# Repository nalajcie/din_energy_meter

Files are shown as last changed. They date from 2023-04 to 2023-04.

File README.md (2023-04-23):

# DIN Energy Meter

**this is Work In Progress, not yet stable HW/SW**

DIN Energy Meter fitting 2-unit enclosure. Features
 - 6-circuit 3-phase 
 - CT-based (external current transformers needed)
 - ESP32 as a main MCU (WiFi)
 - ATM90E32 x2 as a metering IC
 - optional display + buttons

# Hardware

TODO: 3D model of full device
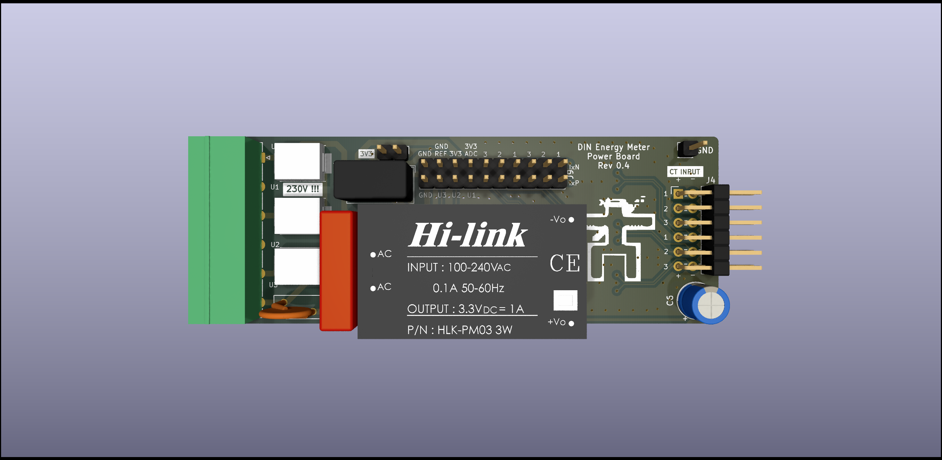
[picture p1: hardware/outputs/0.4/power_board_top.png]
Power Board top side

For details see [Hardware README](hardware/README.md)

# Current status

## Hardware

   - **Power board** - v0.4 prototype (not assembled)
   - **Metering board** - v0.4 prototype (assembled, in test)
   - **MCU board** - breadboard prototyping

## Software
   - basic **Metering board** test with Arduino framework done

# Inspiration

This project is heavily inspired by previous work, mainly:
 - [DIN_Rail_EnergyMonitor](https://github.com/whatnick/DIN_Rail_EnergyMonitor/) by [@whatnick](https://github.com/whatnick)
 - [Expandable 6 Channel ESP32 Energy Meter](https://github.com/CircuitSetup/Expandable-6-Channel-ESP32-Energy-Meter) by [CircuitSetup](https://github.com/CircuitSetup)

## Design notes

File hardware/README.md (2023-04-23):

# Kicad project of DIN Energy Meter

TODO: describe how to import into clean KiCad

Done in KiCad 7.0, multi-board design in hierarchical sheet. Splitting to multiple boards is done by kikit (see `split_boards.sh` for details).

# Power Board

 - Single-phase 230V AC to 3v3 DC
 - isolated 3v3 to 3v3 for power separation between ADCs and MCU
 - fliters and burden resistors for CT input
 - 2x10 2.54mm GPIO header for connecting with the **Metering Board**

Top side
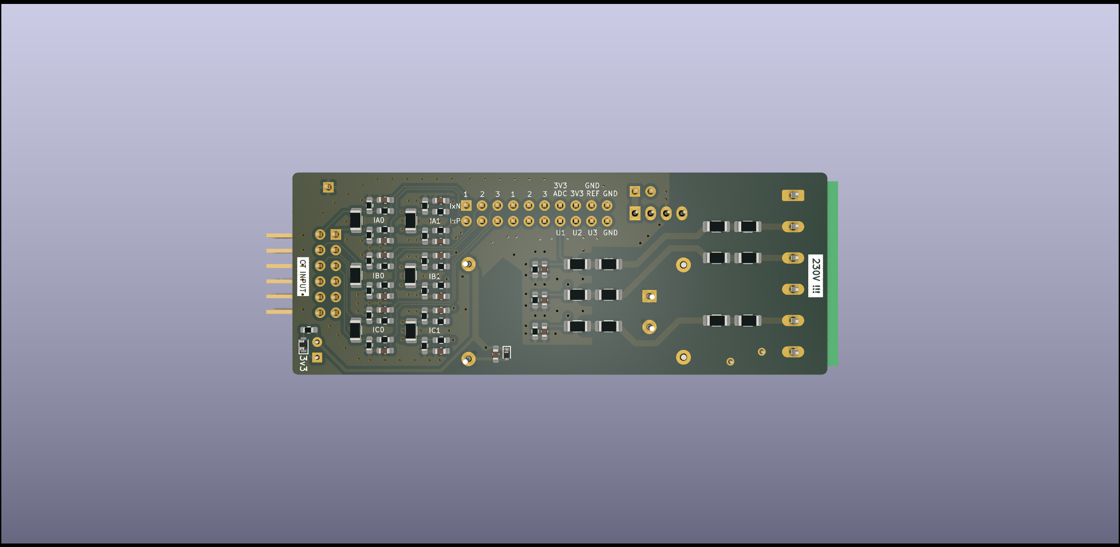
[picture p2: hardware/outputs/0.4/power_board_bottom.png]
Bottom side


# Metering Board

 - 2x ATM90E32 for energy measurement
 - CF1/2 on GPIO headers for accuracy measurement (CF3/4 on testpoints)
 - Power Manager selectors on solder jumpers
 - isolated SPI for MCU connection
 - 2x10 2.54mm GPIO header for connecting with the **Power Board**
 - 1x10 2.54mm GPIO header for connection with the **MCU board**

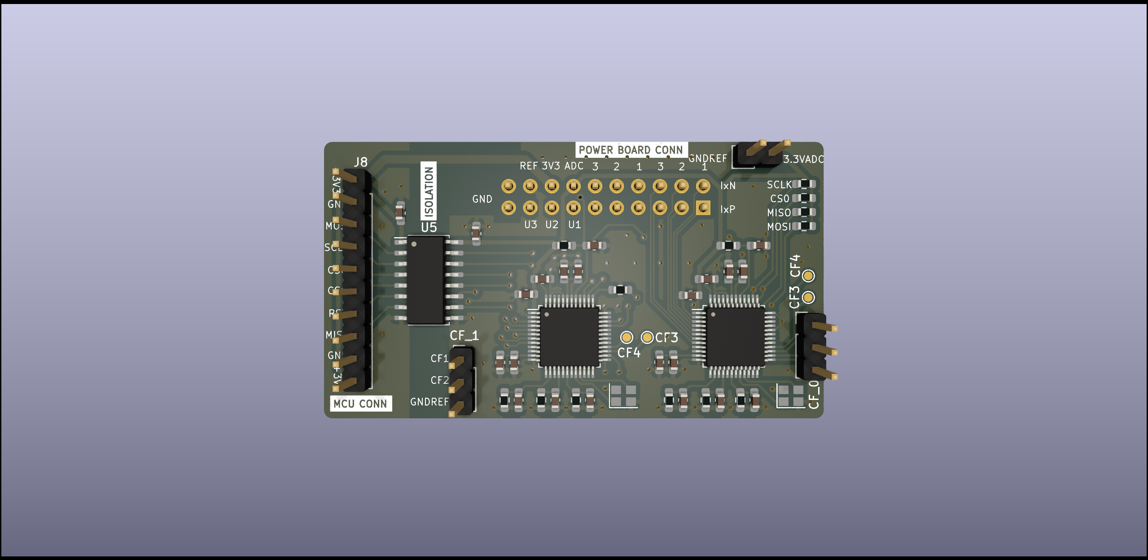
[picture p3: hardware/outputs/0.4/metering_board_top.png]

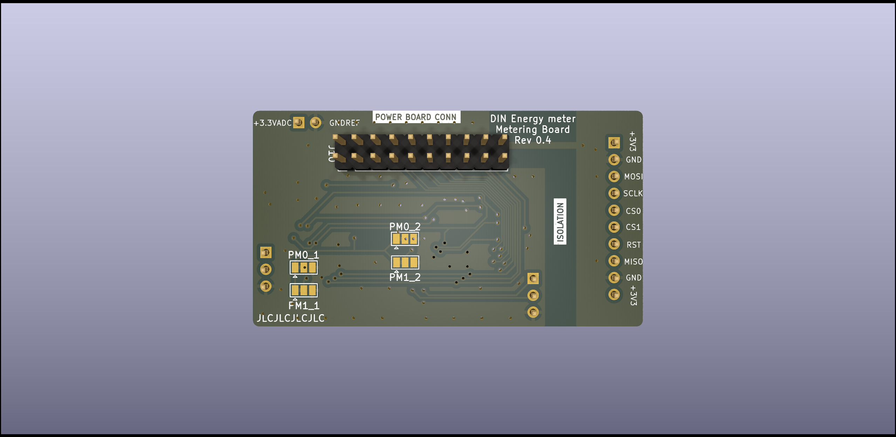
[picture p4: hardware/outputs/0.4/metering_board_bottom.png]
Botom side


# MCU Board

TODO

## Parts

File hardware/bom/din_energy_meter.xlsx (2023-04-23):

Prj: | din_energy_meter.xml |  |  |  | Board Qty: | 100
Co.: |  |  |  |  | Unit Cost: | $15.43
Prj date: | sob, 25 lut 2023, 14:41:14 |  |  |  | Total Cost: | $1543.05 |  |  |  |  | $1176.33 | 11 of 31 parts found |  |  |  |  | $1554.29 | 14 of 31 parts found |  |  |  |  | $1255.61 | 10 of 31 parts found |  |  |  |  | $0.00 | 0 of 31 parts found |  |  |  |  | $1572.30 | 16 of 31 parts found |  |  |  |  | $1421.20 | 13 of 31 parts found |  |  |  |  | $1427.90 | 6 of 31 parts found |  |  |  |  | $570.98 | 18 of 31 parts found
$ date: | 2023-02-25 14:41:14
Global Part Info |  |  |  |  |  |  | Arrow |  |  |  |  |  | Digi-Key |  |  |  |  |  | Farnell |  |  |  |  |  | LCSC |  |  |  |  |  | Mouser |  |  |  |  |  | Newark |  |  |  |  |  | RS Components |  |  |  |  |  | TME
Refs | Value | Footprint | Manf# | Qty | Unit$ | Ext$ | Avail | Purch | Unit$ | MOQ | Ext$ | Cat# | Avail | Purch | Unit$ | MOQ | Ext$ | Cat# | Avail | Purch | Unit$ | MOQ | Ext$ | Cat# | Avail | Purch | Unit$ | MOQ | Ext$ | Cat# | Avail | Purch | Unit$ | MOQ | Ext$ | Cat# | Avail | Purch | Unit$ | MOQ | Ext$ | Cat# | Avail | Purch | Unit$ | MOQ | Ext$ | Cat# | Avail | Purch | Unit$ | MOQ | Ext$ | Cat#
C1 | X2 100nF/275Vac | C_Rect_L18.0mm_W5.0mm_P15.00mm_FKS3_FKP3 | R46KI3100JHM1K | 100 | $0.194 | $19.40 |  |  |  |  |  |  | 1829 |  | $0.206 | 1 | $20.59 | 399-R46KI3100JHM1K-ND (https://octopart.com/click/track?ai=8078&sig=0d9e435&sid=459&ppid=20014343&vpid=658234598&ct=offers) | NonStk |  |  | 2000 |  | 2936551 (https://octopart.com/click/track?c=1&ai=8078&sig=0a215c6&sid=819&ppid=20014343&vpid=508109401&ct=offers) |  |  |  |  |  |  | 598 |  | $0.194 | 1 | $19.40 | 80-R46KI3100JHM1K (https://octopart.com/click/track?ai=8078&sig=02b7bfd&sid=2401&ppid=20014343&vpid=40138411&ct=offers) | NonStk |  |  | 2000 |  | 91AC0455 (https://octopart.com/click/track?c=1&ai=8078&sig=0f080cc&sid=2402&ppid=20014343&vpid=524279401&ct=offers)
C2 | 1uF | C_0603_1608Metric_Pad1.08x0.95mm_HandSolder | 0603B105K100CT | 100 | $0.019 | $1.90 | 32000 |  |  | 4000 |  | 0603B105K100CT (https://octopart.com/click/track?ai=8078&sig=085925f&sid=1106&ppid=23395230&vpid=435019830&ct=offers) | 19302 |  | $0.036 | 1 | $3.56 | 1292-0603B105K100CT-ND (https://octopart.com/click/track?ai=8078&sig=02cb6c4&sid=459&ppid=23395230&vpid=752151002&ct=offers) | 44000 |  | $0.043 | 10 | $4.31 | 3764119 (https://octopart.com/click/track?ai=8078&sig=0e46b60&sid=819&ppid=23395230&vpid=828845308&ct=offers) |  |  |  |  |  |  | 125 |  | $0.036 | 1 | $3.60 | 791-0603B105K100CT (https://octopart.com/click/track?ai=8078&sig=07ec92e&sid=2401&ppid=23395230&vpid=531631462&ct=offers) | 44000 |  | $0.019 | 1 | $1.90 | 50AJ6304 (https://octopart.com/click/track?ai=8078&sig=0c6b5c1&sid=2402&ppid=23395230&vpid=719400762&ct=offers) |  |  |  |  |  |  | 25900 |  | $0.023 | 100 | $2.26 | 0603B105K100CT (https://octopart.com/click/track?ai=8078&sig=080ccdd&sid=1532&ppid=23395230&vpid=709247350&ct=offers)
C3-C5,C10,C12,C15,C26,C28,C31,C39-C50 | 18nF | C_0603_1608Metric_Pad1.08x0.95mm_HandSolder | VJ0603Y183JXACW1BC | 2100 | $0.029 | $59.92 | 3590 |  | $0.050 | 1 | $103.95 | VJ0603Y183JXACW1BC (https://octopart.com/click/track?ai=8078&sig=0bca6ad&sid=1106&ppid=44635118&vpid=473543330&ct=offers) | 3810 |  | $0.078 | 1 | $164.35 | 720-VJ0603Y183JXACW1BCCT-ND (https://octopart.com/click/track?ai=8078&sig=06d9179&sid=459&ppid=44635118&vpid=720444692&ct=offers) |  |  |  |  |  |  |  |  |  |  |  |  | 3494 |  | $0.079 | 1 | $165.90 | 77-VJ0603Y183JXACBC (https://octopart.com/click/track?ai=8078&sig=06e8837&sid=2401&ppid=44635118&vpid=120235442&ct=offers) | NonStk |  |  | 4000 |  | 38AH3190 (https://octopart.com/click/track?c=1&ai=8078&sig=09761bd&sid=2402&ppid=44635118&vpid=588784234&ct=offers) |  |  |  |  |  |  | 4100 |  | $0.029 | 100 | $59.92 | VJ0603Y183JXACW1BC (https://octopart.com/click/track?ai=8078&sig=0d71c76&sid=1532&ppid=44635118&vpid=709245379&ct=offers)
C6 | 100uF | CP_Radial_D6.3mm_P2.50mm | ECEA0JKS101 | 100 | $0.101 | $10.08 | 2540 |  | $0.101 | 1 | $10.08 | ECE-A0JKS101 (https://octopart.com/click/track?ai=8078&sig=0f45c19&sid=1106&ppid=39480107&vpid=473390767&ct=offers) | 83067 |  | $0.153 | 1 | $15.30 | P958-ND (https://octopart.com/click/track?ai=8078&sig=0bcf554&sid=459&ppid=39480107&vpid=115650943&ct=offers) | 5006 |  | $0.128 | 1 | $12.82 | 1901988 (https://octopart.com/click/track?ai=8078&sig=0d6ed47&sid=11744&ppid=39480107&vpid=132556259&ct=offers) |  |  |  |  |  |  | NonStk |  | $0.122 | 1 | $12.20 | 667-ECE-A0JKS101 (https://octopart.com/click/track?c=1&ai=8078&sig=0b64973&sid=2401&ppid=39480107&vpid=116510917&ct=offers) | 37 |  | $0.131 | 1 | $13.10 | 55T0198 (https://octopart.com/click/track?ai=8078&sig=0df52cc&sid=2402&ppid=39480107&vpid=115392437&ct=offers) | 5135 |  | $0.158 | 5 | $15.81 | 116767 (https://octopart.com/click/track?ai=8078&sig=0fe3259&sid=10022&ppid=39480107&vpid=199096295&ct=offers) | 930 |  | $0.129 | 10 | $12.94 | ECEA0JKS101 (https://octopart.com/click/track?ai=8078&sig=0db0431&sid=1532&ppid=39480107&vpid=709128352&ct=offers)
C7,C23 | 4.7uF | C_0603_1608Metric_Pad1.08x0.95mm_HandSolder | 0603X475K100CT | 200 | $0.023 | $4.53 |  |  |  |  |  |  | 3990 |  | $0.058 | 1 | $11.52 | 1292-0603X475K100CT-ND (https://octopart.com/click/track?ai=8078&sig=0f582cf&sid=459&ppid=23760611&vpid=751474041&ct=offers) | NonStk |  | $0.049 | 10 | $9.82 | 2496929 (https://octopart.com/click/track?c=1&ai=8078&sig=0838894&sid=819&ppid=23760611&vpid=238084392&ct=offers) |  |  |  |  |  |  | 8157 |  | $0.060 | 1 | $12.00 | 791-0603X475K100CT (https://octopart.com/click/track?ai=8078&sig=07a0b57&sid=2401&ppid=23760611&vpid=531631706&ct=offers) |  |  |  |  |  |  |  |  |  |  |  |  | 63800 |  | $0.023 | 100 | $4.53 | 0603X475K100CT (https://octopart.com/click/track?ai=8078&sig=0551518&sid=1532&ppid=23760611&vpid=709247440&ct=offers)
C8,C9,C11,C14,C16-C18,C24,C25,C27,C30,C32 | 100nF | C_0603_1608Metric_Pad1.08x0.95mm_HandSolder | 06033C104KAT2A | 1200 | $0.010 | $11.64 | 8400 |  |  | 4000 |  | 06033C104KAT2A (https://octopart.com/click/track?ai=8078&sig=096d4ad&sid=1106&ppid=39590598&vpid=770669375&ct=offers) | 2354976 |  | $0.010 | 1 | $11.66 | 478-3714-1-ND (https://octopart.com/click/track?ai=8078&sig=069d21e&sid=459&ppid=39590598&vpid=770903829&ct=offers) | 472000 |  | $0.022 | 10 | $26.30 | 2530141 (https://octopart.com/click/track?ai=8078&sig=0d840be&sid=11744&ppid=39590598&vpid=772886336&ct=offers) |  |  |  |  |  |  | 858866 |  | $0.010 | 1 | $12.00 | 581-06033C104KAT2A (https://octopart.com/click/track?ai=8078&sig=0f1bb4d&sid=2401&ppid=39590598&vpid=771169314&ct=offers) | 364753 |  | $0.015 | 1 | $18.00 | 96M1263 (https://octopart.com/click/track?ai=8078&sig=06c45c6&sid=2402&ppid=39590598&vpid=772844523&ct=offers) | 248000 |  | $0.036 | 1000 | $43.12 | 1356595 (https://octopart.com/click/track?ai=8078&sig=0fe29cb&sid=10022&ppid=39590598&vpid=500983576&ct=offers) | 16200 |  | $0.010 | 100 | $11.64 | 06033C104KAT2A (https://octopart.com/click/track?ai=8078&sig=0d59a35&sid=1532&ppid=39590598&vpid=769977700&ct=offers)
C13,C29 | 10uF | C_0603_1608Metric_Pad1.08x0.95mm_HandSolder | 0603X106K6R3CT | 200 | $0.025 | $5.08 | 132000 |  |  | 4000 |  | 0603X106K6R3CT (https://octopart.com/click/track?ai=8078&sig=0fa8e71&sid=1106&ppid=50418793&vpid=418195488&ct=offers) | 31980 |  | $0.125 | 1 | $25.06 | 1292-0603X106K6R3CT-ND (https://octopart.com/click/track?ai=8078&sig=081b751&sid=459&ppid=50418793&vpid=752151067&ct=offers) | 20000 |  | $0.144 | 10 | $28.75 | 3764145 (https://octopart.com/click/track?ai=8078&sig=0025fef&sid=819&ppid=50418793&vpid=828845351&ct=offers) |  |  |  |  |  |  | 4000 |  | $0.130 | 1 | $26.00 | 791-0603X106K6R3CT (https://octopart.com/click/track?ai=8078&sig=0c4db15&sid=2401&ppid=50418793&vpid=531631688&ct=offers) | 20000 |  |  | 4000 |  | 50AJ6327 (https://octopart.com/click/track?ai=8078&sig=06d308f&sid=2402&ppid=50418793&vpid=719400785&ct=offers) |  |  |  |  |  |  | 3730 |  | $0.025 | 10 | $5.08 | 0603X106K6R3CT (https://octopart.com/click/track?ai=8078&sig=043e844&sid=1532&ppid=50418793&vpid=878166210&ct=offers)
D1 | D_TVS | D_SOD-523 | ESD5Z3V3 | 100 | $0.031 | $3.05 |  |  |  |  |  |  |  |  |  |  |  |  |  |  |  |  |  |  |  |  |  |  |  |  | 12308 |  | $0.182 | 1 | $18.20 | 637-ESD5Z3V3 (https://octopart.com/click/track?ai=8078&sig=066cd02&sid=2401&ppid=93126590&vpid=808546162&ct=offers) |  |  |  |  |  |  |  |  |  |  |  |  | 1450 |  | $0.031 | 20 | $3.05 | ESD5Z3V3-DIO (https://octopart.com/click/track?ai=8078&sig=0500459&sid=1532&ppid=93126590&vpid=707850701&ct=offers)
D2 | 3v3 | D_0603_1608Metric | RF-GNB191TS-CF | 100 | $0.039 | $3.86 |  |  |  |  |  |  |  |  |  |  |  |  |  |  |  |  |  |  |  |  |  |  |  |  |  |  |  |  |  |  |  |  |  |  |  |  |  |  |  |  |  |  | 8668 |  | $0.039 | 10 | $3.86 | RF-GNB191TS-CF (https://octopart.com/click/track?ai=8078&sig=0cbc811&sid=1532&ppid=117692161&vpid=712317848&ct=offers)
F1 | 120mA polyfuse | Fuse_BelFuse_0ZRE0012FF_L8.3mm_W3.8mm | 0ZRE0012FF1C (https://www.tme.eu/Document/907938f7193985bd7926321a5eeb36df/0ZRE+Sep2016.pdf) | 100 | $0.236 | $23.62 | 5988 |  | $0.236 | 1 | $23.62 | 0ZRE0012FF1C (https://octopart.com/click/track?ai=8078&sig=0877e9d&sid=1106&ppid=16963854&vpid=104967227&ct=offers) | 15684 |  | $0.276 | 1 | $27.62 | 507-1350-ND (https://octopart.com/click/track?ai=8078&sig=06a94dc&sid=459&ppid=16963854&vpid=33596542&ct=offers) |  |  |  |  |  |  |  |  |  |  |  |  | 8266 |  | $0.277 | 1 | $27.70 | 530-0ZRE0012FF1C (https://octopart.com/click/track?ai=8078&sig=084db7e&sid=2401&ppid=16963854&vpid=210394555&ct=offers) | NonStk |  |  | 2000 |  | 58AC4734 (https://octopart.com/click/track?c=1&ai=8078&sig=0ab400e&sid=2402&ppid=16963854&vpid=508524160&ct=offers) |  |  |  |  |  |  | 798 |  | $0.250 | 5 | $25.03 | 0ZRE0012FF1C (https://octopart.com/click/track?ai=8078&sig=0e4f024&sid=1532&ppid=16963854&vpid=707800490&ct=offers)
IC1,IC2 | ATM90E32AS | TQFP-48_7x7mm_P0.5mm | ATM90E36A-AU-Y (http://ww1.microchip.com/downloads/en/devicedoc/Atmel-46003-SE-M90E32AS-Datasheet.pdf) | 200 | $4.765 | $953.00 | 8 |  | $4.765 | 1 | $953.00 | ATM90E36A-AU-Y (https://octopart.com/click/track?ai=8078&sig=0fd6b16&sid=1106&ppid=77759767&vpid=473293160&ct=offers) | NonStk |  | $4.800 | 1 | $960.00 | ATM90E36A-AU-Y-ND (https://octopart.com/click/track?ai=8078&sig=0e8341e&sid=459&ppid=77759767&vpid=408716065&ct=offers) | 490 |  | $5.055 | 1 | $1010.94 | 2851659 (https://octopart.com/click/track?ai=8078&sig=0a1cbe9&sid=11744&ppid=77759767&vpid=478775971&ct=offers) |  |  |  |  |  |  | NonStk |  | $4.800 | 1 | $960.00 | 556-ATM90E36A-AU-Y (https://octopart.com/click/track?c=1&ai=8078&sig=0b3a90c&sid=2401&ppid=77759767&vpid=408978359&ct=offers) | 490 |  | $4.800 | 1 | $960.00 | 55AC1236 (https://octopart.com/click/track?ai=8078&sig=0ea5cb5&sid=2402&ppid=77759767&vpid=477464294&ct=offers) | 304 |  | $5.767 | 2 | $1153.48 | 1773688P (https://octopart.com/click/track?ai=8078&sig=0ebb1fb&sid=10022&ppid=77759767&vpid=576284179&ct=offers) | NonStk |  |  | 250 |  | ATM90E36A-AU-Y (https://octopart.com/click/track?c=1&ai=8078&sig=0d923a4&sid=1532&ppid=77759767&vpid=709079543&ct=offers)
J1 | PWR | PinHeader_1x02_P2.54mm_Vertical |  | 100
J2 | PHASE_CONN | PhoenixContact_MC_1,5_6-G-5.08_1x06_P5.08mm_Horizontal |  | 100
J3 | GNDREF | PinHeader_1x01_P2.54mm_Vertical |  | 100
J4 | Conn_02x06_Odd_Even | PinHeader_2x06_P2.54mm_Horizontal |  | 100
J7,J11 | CF_${IC} | PinHeader_1x03_P2.54mm_Vertical |  | 200
J8 | MCU_CONN | PinHeader_1x10_P2.54mm_Vertical |  | 100
J9,J10 | PowerBoard | PinHeader_2x10_P2.54mm_Vertical |  | 200
J12 | Conn_01x02 | PinHeader_1x02_P2.54mm_Vertical |  | 100
L1 | 270 nH | L_1206_3216Metric | AIML-1206-R27K-T | 100 | $0.088 | $8.82 | 21983 |  | $0.088 | 1 | $8.82 | AIML-1206-R27K-T (https://octopart.com/click/track?ai=8078&sig=0644fb9&sid=1106&ppid=20100824&vpid=507086374&ct=offers) | 14846 |  | $0.189 | 1 | $18.89 | 535-11684-1-ND (https://octopart.com/click/track?ai=8078&sig=05738c4&sid=459&ppid=20100824&vpid=44466968&ct=offers) |  |  |  |  |  |  |  |  |  |  |  |  | 23804 |  | $0.151 | 1 | $15.10 | 815-AIML-1206-R27KT (https://octopart.com/click/track?ai=8078&sig=0473fb4&sid=2401&ppid=20100824&vpid=269003347&ct=offers) | NonStk |  |  | 30000 |  | 96W8210 (https://octopart.com/click/track?c=1&ai=8078&sig=0ca56a2&sid=2402&ppid=20100824&vpid=95831973&ct=offers)
PS1 | HLK-PM03 | Converter_ACDC_HiLink_HLK-PMxx | HLK-PM03 (http://www.hlktech.net/product_detail.php?ProId=59) | 100
PS2 | AM1SS-0303S | Converter_DCDC_SIP4_THT | AM1SS-0303S-NZ (https://power.murata.com/pub/data/power/ncl/kdc_mee1.pdf) | 100 | $2.276 | $227.58 |  |  |  |  |  |  |  |  |  |  |  |  |  |  |  |  |  |  |  |  |  |  |  |  |  |  |  |  |  |  | NonStk |  | $2.440 | 1 | $244.00 | 27AK8762 (https://octopart.com/click/track?c=1&ai=8078&sig=0dc0d35&sid=2402&ppid=47202323&vpid=801580070&ct=offers) |  |  |  |  |  |  | 238 |  | $2.276 | 1 | $227.58 | AM1SS-0303S-NZ (https://octopart.com/click/track?ai=8078&sig=0dd2fc3&sid=1532&ppid=47202323&vpid=707755244&ct=offers)
R1-R12 | 220K | R_1206_3216Metric_Pad1.30x1.75mm_HandSolder | ARG06DTC2203 | 1200 | $0.017 | $20.45 |  |  |  |  |  |  |  |  |  |  |  |  |  |  |  |  |  |  |  |  |  |  |  |  |  |  |  |  |  |  |  |  |  |  |  |  |  |  |  |  |  |  | 5000 |  | $0.017 | 100 | $20.45 | ARG1206-220K-0.5% (https://octopart.com/click/track?ai=8078&sig=0355751&sid=1532&ppid=81881808&vpid=709238049&ct=offers)
R13-R18,R34-R36,R72-R77,R87-R92 | 1K | R_0603_1608Metric_Pad0.98x0.95mm_HandSolder | AC0603FR-071KL | 2100 | $0.004 | $9.16 | 10000 |  | $0.037 | 1 | $76.86 | AC0603FR-071KL (https://octopart.com/click/track?ai=8078&sig=0da5267&sid=1106&ppid=21711097&vpid=712942385&ct=offers) | 787994 |  | $0.005 | 1 | $9.72 | 311-1KLDCT-ND (https://octopart.com/click/track?ai=8078&sig=0beb677&sid=459&ppid=21711097&vpid=48251721&ct=offers) | 694910 |  | $0.005 | 10 | $10.06 | 3495238 (https://octopart.com/click/track?ai=8078&sig=02465d4&sid=819&ppid=21711097&vpid=653862114&ct=offers) |  |  |  |  |  |  | 1569620 |  | $0.005 | 1 | $10.50 | 603-AC0603FR-071KL (https://octopart.com/click/track?ai=8078&sig=0c7dd51&sid=2401&ppid=21711097&vpid=47327394&ct=offers) | 696330 |  | $0.009 | 1 | $18.90 | 49AK0481 (https://octopart.com/click/track?c=1&ai=8078&sig=08c4470&sid=2402&ppid=21711097&vpid=833155641&ct=offers) | 76000 |  | $0.012 | 500 | $25.15 | 1978033 (https://octopart.com/click/track?ai=8078&sig=042dc69&sid=10022&ppid=21711097&vpid=625435411&ct=offers) | 48300 |  | $0.004 | 100 | $9.16 | AC0603FR-071KL (https://octopart.com/click/track?ai=8078&sig=0dff357&sid=1532&ppid=21711097&vpid=709256810&ct=offers)
R19,R37,R52-R56 | 10K | R_0603_1608Metric_Pad0.98x0.95mm_HandSolder | AC0603FR-0710KL | 700 | $0.009 | $6.30 | 44979 |  |  | 5000 |  | AC0603FR-0710KL (https://octopart.com/click/track?ai=8078&sig=078ca9b&sid=1106&ppid=21711091&vpid=525146659&ct=offers) | 1620273 |  | $0.010 | 1 | $7.21 | 311-10KLDCT-ND (https://octopart.com/click/track?ai=8078&sig=048749f&sid=459&ppid=21711091&vpid=48251715&ct=offers) | 1066430 |  | $0.010 | 10 | $6.71 | 3495224 (https://octopart.com/click/track?ai=8078&sig=035a96c&sid=819&ppid=21711091&vpid=653862088&ct=offers) |  |  |  |  |  |  | 1315817 |  | $0.011 | 1 | $7.70 | 603-AC0603FR-0710KL (https://octopart.com/click/track?ai=8078&sig=0890030&sid=2401&ppid=21711091&vpid=47327388&ct=offers) | 1050430 |  | $0.009 | 1 | $6.30 | 82AH6475 (https://octopart.com/click/track?ai=8078&sig=08fa70f&sid=2402&ppid=21711091&vpid=655849759&ct=offers) | 41500 |  | $0.013 | 500 | $9.22 | 1978014 (https://octopart.com/click/track?ai=8078&sig=062ae61&sid=10022&ppid=21711091&vpid=625435384&ct=offers) | 68300 |  | $0.015 | 100 | $10.82 | AC0603FR-0710KL (https://octopart.com/click/track?ai=8078&sig=0df3789&sid=1532&ppid=21711091&vpid=709256805&ct=offers)
R22 | 27 | R_0603_1608Metric_Pad0.98x0.95mm_HandSolder | 0603SAF270JT5E | 100 | $0.013 | $1.32 |  |  |  |  |  |  |  |  |  |  |  |  |  |  |  |  |  |  |  |  |  |  |  |  | NonStk |  |  | 10000 |  | 303-0603SAF270JT5E (https://octopart.com/click/track?c=1&ai=8078&sig=07bcc4d&sid=2401&ppid=50586927&vpid=848260658&ct=offers) |  |  |  |  |  |  |  |  |  |  |  |  | 213700 |  | $0.013 | 100 | $1.32 | SMD0603-27R-1% (https://octopart.com/click/track?ai=8078&sig=099bb44&sid=1532&ppid=50586927&vpid=709151428&ct=offers)
R63-R65,R78-R80 | 20 | R_1206_3216Metric | ARG06DTC0200 | 600 | $0.031 | $18.69 |  |  |  |  |  |  |  |  |  |  |  |  |  |  |  |  |  |  |  |  |  |  |  |  |  |  |  |  |  |  |  |  |  |  |  |  |  |  |  |  |  |  | 9100 |  | $0.031 | 100 | $18.69 | ARG1206-20R-0.5% (https://octopart.com/click/track?ai=8078&sig=08034d3&sid=1532&ppid=117725499&vpid=716008692&ct=offers)
R66-R71,R81-R86 | 2.4 | R_0603_1608Metric_Pad0.98x0.95mm_HandSolder |  | 1200
RV1-RV3 | 275 VAC | CU3225 | B72650M0271K072 | 300 | $0.188 | $56.52 | 5000 |  |  | 1000 |  | B72650M0271K072 (https://octopart.com/click/track?ai=8078&sig=0b6aa59&sid=1106&ppid=11760851&vpid=864848381&ct=offers) | 42434 |  | $0.580 | 1 | $174.02 | 495-2388-1-ND (https://octopart.com/click/track?ai=8078&sig=0add487&sid=459&ppid=11760851&vpid=441542126&ct=offers) | 1994 |  | $0.486 | 1 | $145.89 | 9958533 (https://octopart.com/click/track?ai=8078&sig=064fd41&sid=11744&ppid=11760851&vpid=194181755&ct=offers) |  |  |  |  |  |  | 46843 |  | $0.530 | 1 | $159.00 | 871-B72650M0271K072 (https://octopart.com/click/track?ai=8078&sig=0b16769&sid=2401&ppid=11760851&vpid=42614561&ct=offers) | NonStk |  | $0.530 | 1 | $159.00 | 34M5347 (https://octopart.com/click/track?c=1&ai=8078&sig=08f2c19&sid=2402&ppid=11760851&vpid=198960057&ct=offers) | 2000 |  | $0.604 | 5 | $181.11 | 7691993 (https://octopart.com/click/track?ai=8078&sig=0aa7f29&sid=10022&ppid=11760851&vpid=229316461&ct=offers) | 19160 |  | $0.188 | 5 | $56.52 | B72650M271K72 (https://octopart.com/click/track?ai=8078&sig=0f6f2ac&sid=1532&ppid=11760851&vpid=707881342&ct=offers)
U5 | Π161M31 | SOIC-16_4.55x10.3mm_P1.27mm | PAI161M31 (https://www.tme.eu/Document/adeb9fdb0591ca86c726a8f870a6b0a3/PAI16xM3x_PAI16xM6x.pdf) | 100
Y1,Y2 | 16.384MHz | Crystal_SMD_2520-4Pin_2.5x2.0mm | LFXTAL069395CUTT (https://www.tme.eu/Document/746e65f8387f34db343fe6d2f6181449/LFXTAL069395CUTT.pdf) | 200 | $0.491 | $98.14 |  |  |  |  |  |  | 16968 |  | $0.524 | 1 | $104.78 | 1923-1355-1-ND (https://octopart.com/click/track?ai=8078&sig=0442bfd&sid=459&ppid=65452348&vpid=705503096&ct=offers) |  |  |  |  |  |  |  |  |  |  |  |  | 65 |  | $0.615 | 1 | $123.00 | 449-LFXTAL069395CUTT (https://octopart.com/click/track?ai=8078&sig=0ca7c83&sid=2401&ppid=65452348&vpid=456356865&ct=offers) |  |  |  |  |  |  |  |  |  |  |  |  | 100 |  | $0.491 | 1 | $98.14 | 16.3840M-CFPX-218 (https://octopart.com/click/track?ai=8078&sig=038e80a&sid=1532&ppid=65452348&vpid=709031548&ct=offers)
 | Used currency rates: |  |  |  | Total Purchase: | $0.00 | Buy here (https://www.arrow.com/en/bom-tool/) |  |  |  | $0.00 |  | Buy here (https://www.digikey.com/ordering/shoppingcart) |  |  |  | $0.00 |  | Buy here (https://fr.farnell.com/en-FR/quick-order?isQuickPaste=true) |  |  |  | $0.00 |  | Buy here (https://lcsc.com/bom.html) |  |  |  | $0.00 |  | Buy here (https://mouser.com/bom/) |  |  |  | $0.00 |  | Buy here (https://www.newark.com/quick-order?isQuickPaste=true) |  |  |  | $0.00 |  | Buy here (https://uk.rs-online.com/web/mylists/manualQuotes.html?method=showEnquiryCreationPage&mode=new) |  |  |  | $0.00 |  | Buy here (https://www.tme.eu/en/Profile/QuickBuy/load.html) |  |  |  | $0.00
 | USD($)/GBP(£): | 1.197801575 |  |  | Purchase description: |  |  |  |  |  |  |  |  |  |  |  |  |  |  |  |  |  |  |  |  | Copy this header and order to a CSV file and use it for JLCPCB manufacturer PCB house. The multipart components that use "#" symbol are not allowed by JLCPCB.
KiCost® v1.1.15

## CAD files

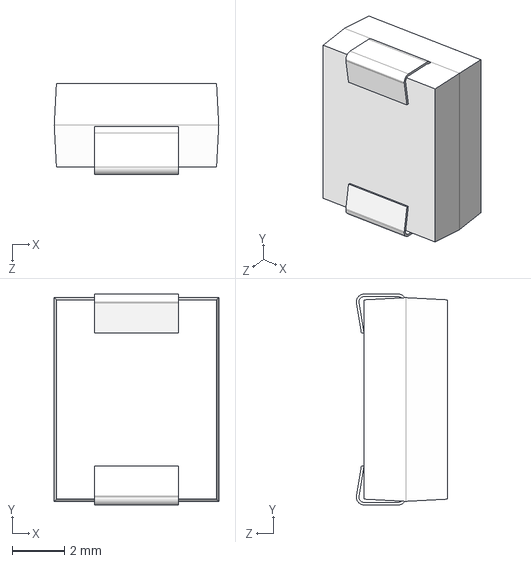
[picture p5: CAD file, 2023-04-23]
hardware/3D/B72650M0271K072.stp
6.30 x 8.08 x 3.49 mm

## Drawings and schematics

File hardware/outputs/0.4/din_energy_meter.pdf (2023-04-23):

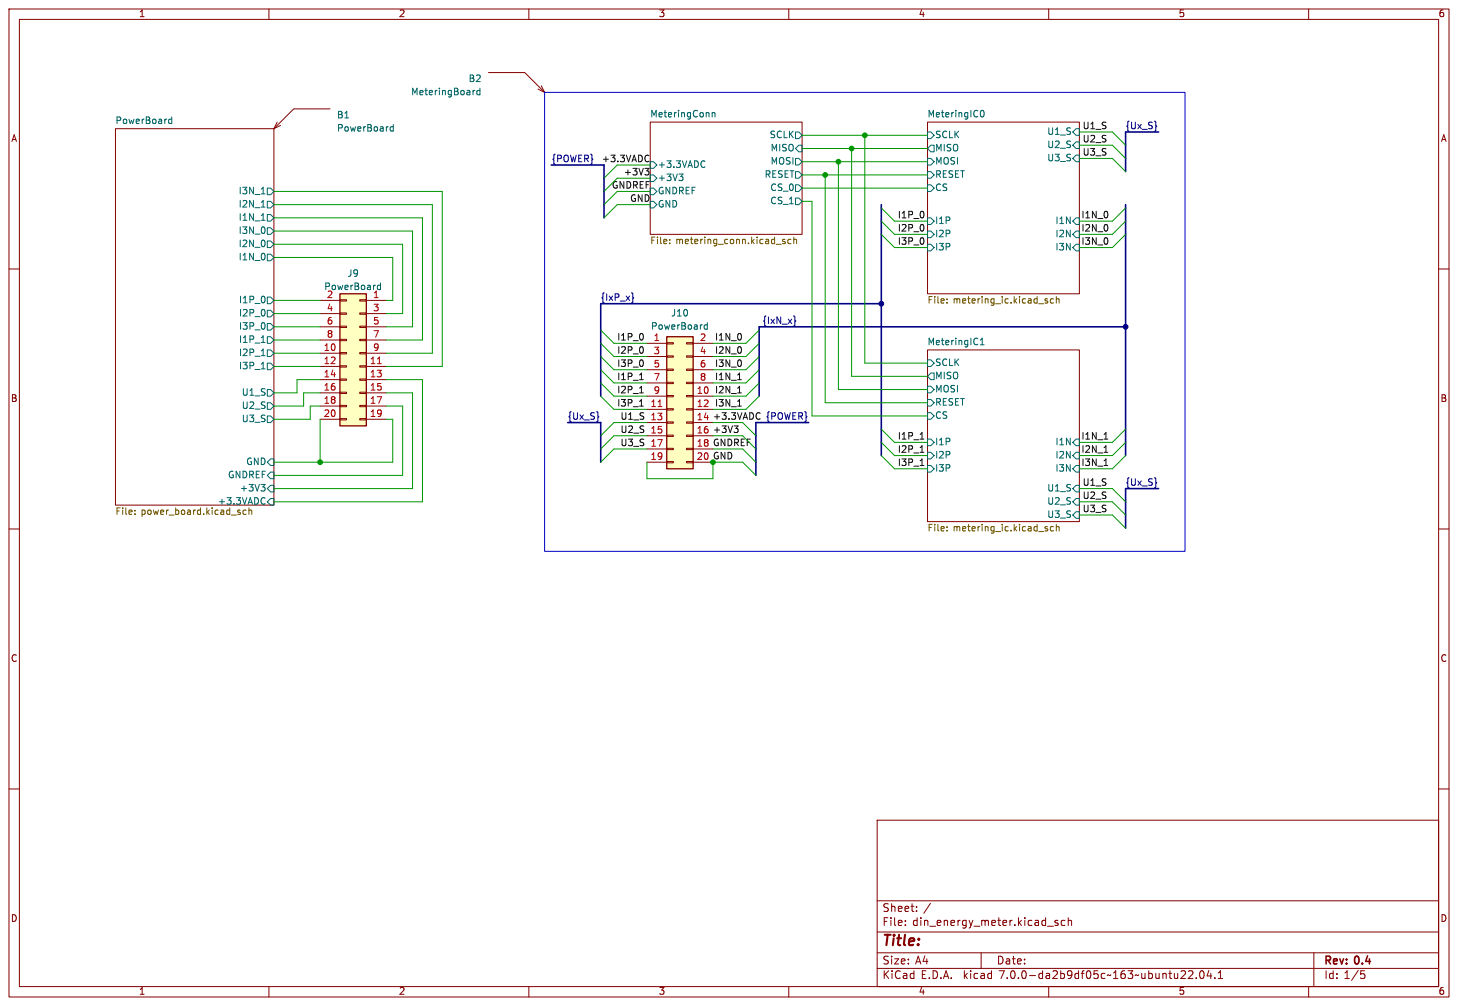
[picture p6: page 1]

CSRESET MeteringIC0 File: metering_ic.kicad_sch SCLK MISO MOSI CS_0 CS_1 +3V3 GND GNDREF

Id: 1/5 Title: File: din_energy_meter.kicad_sch Sheet: /

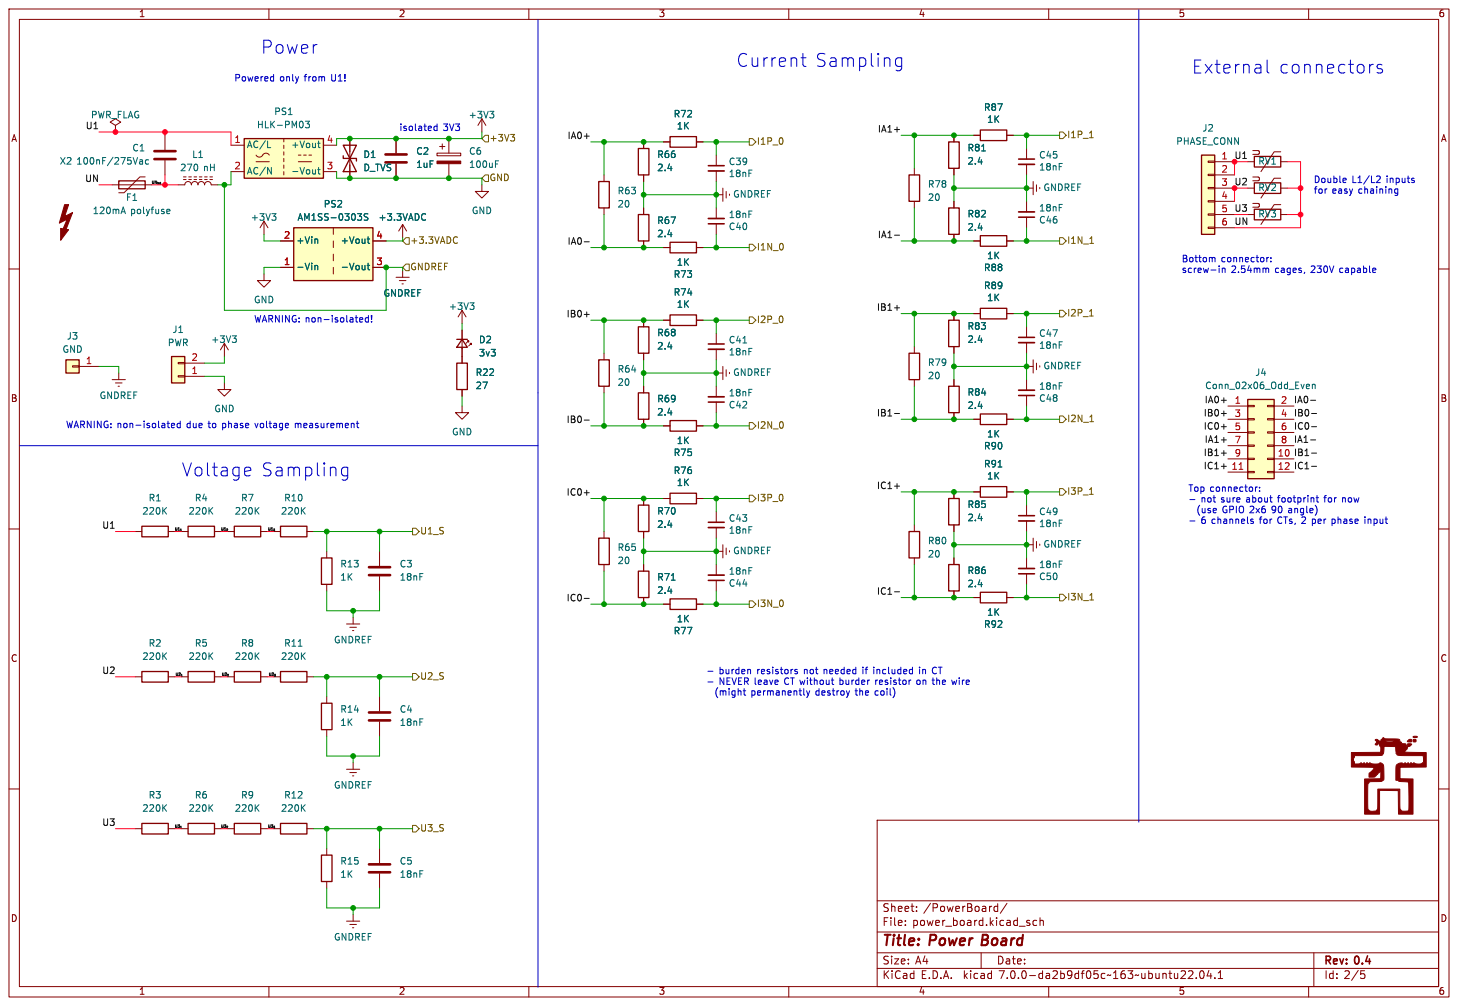
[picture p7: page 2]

- burden resistors not needed if included in CT
- NEVER leave CT without burder resistor on the wire

Id: 2/5 Title: Power Board

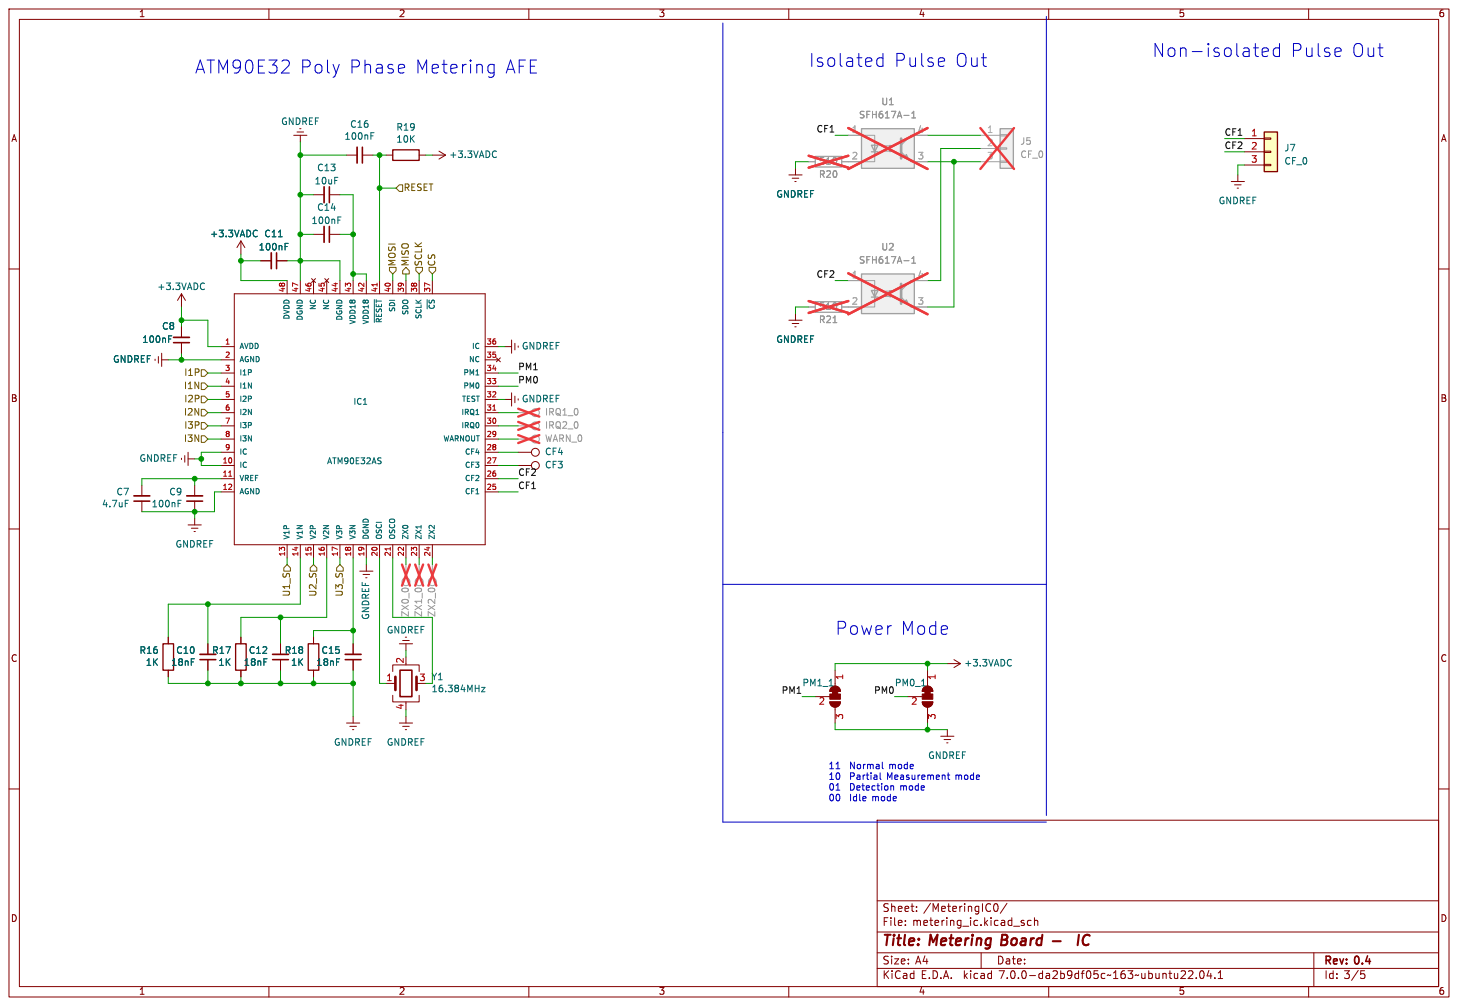
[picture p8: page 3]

00 Idle mode Power Mode

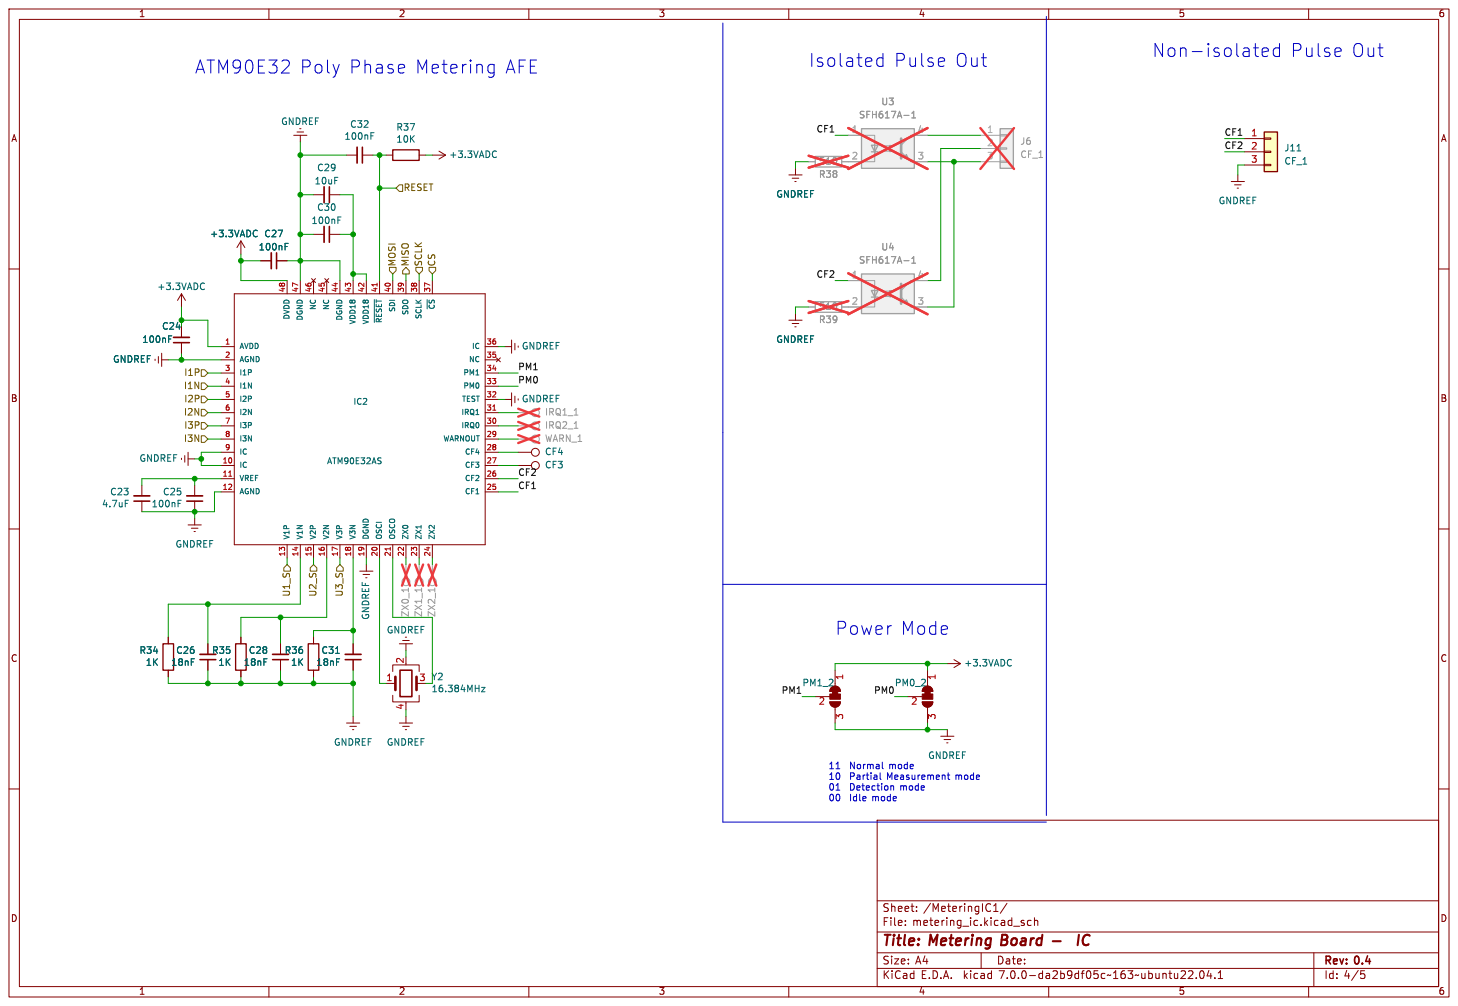
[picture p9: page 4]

ATM90E32 Poly Phase Metering AFE
18nF GNDREF C24

00 Idle mode Power Mode

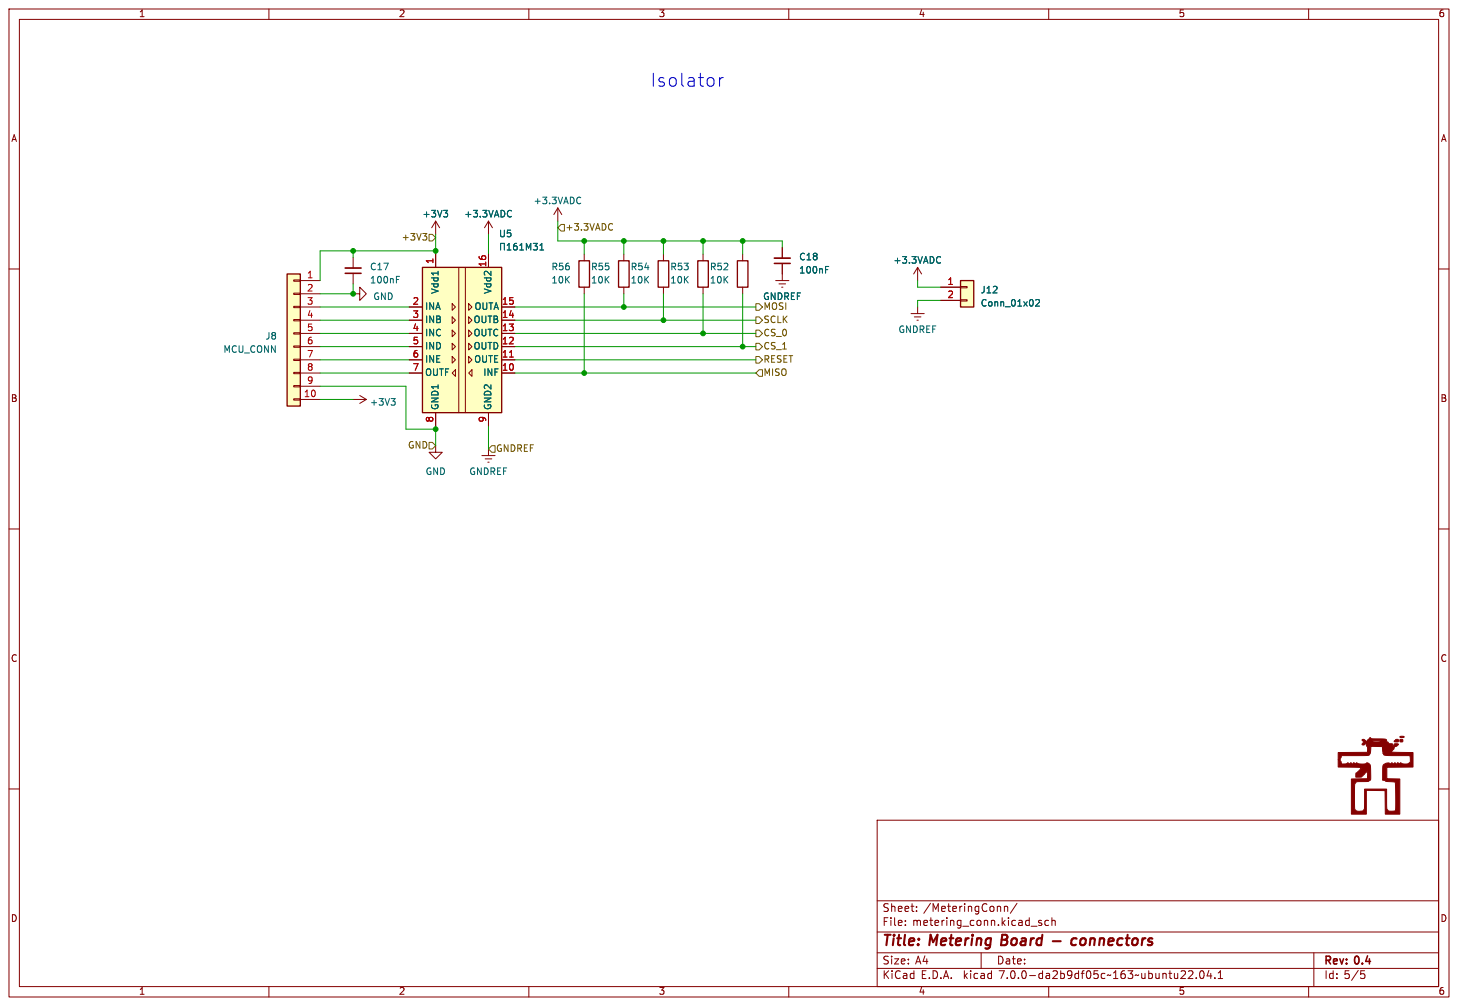
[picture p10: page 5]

File: metering_conn.kicad_sch Sheet: /MeteringConn/
Id: 5/5 Title: Metering Board - connectors

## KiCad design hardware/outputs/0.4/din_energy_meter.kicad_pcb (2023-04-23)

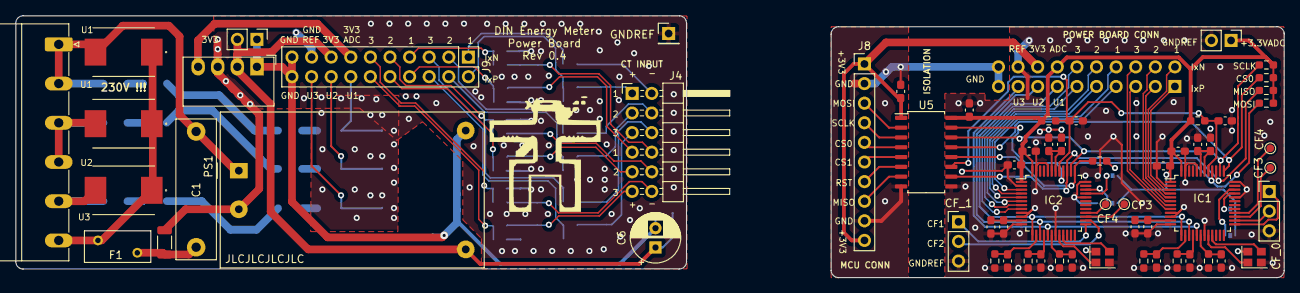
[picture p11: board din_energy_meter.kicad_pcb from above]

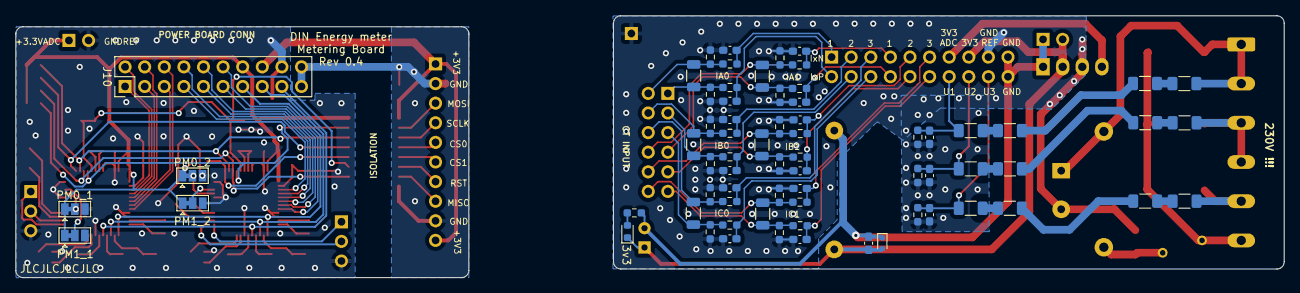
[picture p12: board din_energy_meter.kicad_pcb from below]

Board: 2 copper layers, 164.3 x 33.9 mm, 134 parts (69 on the bottom side), 99 nets.

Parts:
B1: PowerBoard; Board
B2: MeteringBoard; Board
C1: X2 100nF/275Vac; C_Rect_L18.0mm_W5.0mm_P15.00mm_FKS3_FKP3
C2: 1uF; C_0603_1608Metric_Pad1.08x0.95mm_HandSolder
C3, C4, C5, C10, C12, C15, C26, C28, C31, C39, C40, C41, C42, C43, C44, C45, C46, C47, C48, C49, C50: 18nF; C_0603_1608Metric_Pad1.08x0.95mm_HandSolder
C6: 100uF; CP_Radial_D6.3mm_P2.50mm
C7, C23: 4.7uF; C_0603_1608Metric_Pad1.08x0.95mm_HandSolder
C8, C9, C11, C14, C16, C17, C18, C24, C25, C27, C30, C32: 100nF; C_0603_1608Metric_Pad1.08x0.95mm_HandSolder
C13, C29: 10uF; C_0603_1608Metric_Pad1.08x0.95mm_HandSolder
D1: D_TVS; D_SOD-523
D2: 3v3; D_0603_1608Metric
F1: 120mA polyfuse; Fuse_BelFuse_0ZRE0012FF_L8.3mm_W3.8mm
G1: darwiniajack
IC1, IC2: ATM90E32AS; TQFP-48_7x7mm_P0.5mm
J1: PWR; PinHeader_1x02_P2.54mm_Vertical
J2: PHASE_CONN; PhoenixContact_MC_1,5_6-G-5.08_1x06_P5.08mm_Horizontal
J3: GNDREF; PinHeader_1x01_P2.54mm_Vertical
J4: Conn_02x06_Odd_Even; PinHeader_2x06_P2.54mm_Horizontal
J7, J11: CF_${IC}; PinHeader_1x03_P2.54mm_Vertical
J8: MCU_CONN; PinHeader_1x10_P2.54mm_Vertical
J9, J10: PowerBoard; PinHeader_2x10_P2.54mm_Vertical
J12: Conn_01x02; PinHeader_1x02_P2.54mm_Vertical
L1: 270 nH; L_1206_3216Metric
PM0_1, PM0_2, PM1_1, PM1_2: SolderJumper_3_Bridged12; SolderJumper-3_P1.3mm_Bridged12_Pad1.0x1.5mm
PS1: HLK-PM03; Converter_ACDC_HiLink_HLK-PMxx
PS2: AM1SS-0303S; Converter_DCDC_SIP4_THT
R1, R2, R3, R4, R5, R6, R7, R8, R9, R10, R11, R12: 220K; R_1206_3216Metric_Pad1.30x1.75mm_HandSolder
R13, R14, R15, R16, R17, R18, R34, R35, R36, R72, R73, R74, R75, R76, R77, R87, R88, R89, R90, R91, R92: 1K; R_0603_1608Metric_Pad0.98x0.95mm_HandSolder
R19, R37, R52, R53, R54, R55, R56: 10K; R_0603_1608Metric_Pad0.98x0.95mm_HandSolder
R22: 27; R_0603_1608Metric_Pad0.98x0.95mm_HandSolder
R63, R64, R65, R78, R79, R80: 20; R_1206_3216Metric
R66, R67, R68, R69, R70, R71, R81, R82, R83, R84, R85, R86: 2.4; R_0603_1608Metric_Pad0.98x0.95mm_HandSolder
RV1, RV2, RV3: 275 VAC; CU3225
TP2, TP11: CF3; TestPoint_Pad_D1.0mm
TP6, TP15: CF4; TestPoint_Pad_D1.0mm
U5: Π161M31; SOIC-16_4.55x10.3mm_P1.27mm
Y1, Y2: 16.384MHz; Crystal_SMD_2520-4Pin_2.5x2.0mm

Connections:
+3.3VADC: C8.2, C11.2, C18.2, C24.2, C27.2, IC1.1 (AVDD), IC1.48 (DVDD), IC2.1 (AVDD), IC2.48 (DVDD), J9.13, J10.14, J12.1, PM0_1.1 (A), PM0_2.1 (A), PM1_1.1 (A), PM1_2.1 (A), PS2.4 (+Vout), R19.1, R37.1, R52.1, R53.1, R54.1, R55.1, R56.1, U5.16 (Vdd2)
+3V3: C2.1, C6.1, C17.2, D1.2 (A2), D2.1 (K), J1.2, J8.1, J8.10, J9.15, J10.16, PS1.4 (+Vout), PS2.2 (+Vin), U5.1 (Vdd1)
/I1N_0: IC1.4 (I1N), J10.2
/I1N_1: IC2.4 (I1N), J10.8
/I1P_0: IC1.3 (I1P), J10.1
/I1P_1: IC2.3 (I1P), J10.7
/I2N_0: IC1.6 (I2N), J10.4
/I2N_1: IC2.6 (I2N), J10.10
/I2P_0: IC1.5 (I2P), J10.3
/I2P_1: IC2.5 (I2P), J10.9
/I3N_0: IC1.8 (I3N), J10.6
/I3N_1: IC2.8 (I3N), J10.12
/I3P_0: IC1.7 (I3P), J10.5
/I3P_1: IC2.7 (I3P), J10.11
/MeteringConn/CS_0: IC1.37 (~CS), R53.2, U5.13 (OUTC)
/MeteringConn/CS_1: IC2.37 (~CS), R52.2, U5.12 (OUTD)
/MeteringConn/MISO: IC1.39 (SDO), IC2.39 (SDO), R56.2, U5.10 (INF)
/MeteringConn/MOSI: IC1.40 (SDI), IC2.40 (SDI), R55.2, U5.15 (OUTA)
/MeteringConn/RESET: C16.1, C32.1, IC1.41 (~RESET), IC2.41 (~RESET), R19.2, R37.2, U5.11 (OUTE)
/MeteringConn/SCLK: IC1.38 (SCLK), IC2.38 (SCLK), R54.2, U5.14 (OUTB)
/MeteringIC0/CF1: IC1.25 (CF1), J7.1
/MeteringIC0/CF2: IC1.26 (CF2), J7.2
/MeteringIC0/PM0: IC1.33 (PM0), PM0_1.2 (C)
/MeteringIC0/PM1: IC1.34 (PM1), PM1_1.2 (C)
/MeteringIC1/CF1: IC2.25 (CF1), J11.1
/MeteringIC1/CF2: IC2.26 (CF2), J11.2
/MeteringIC1/PM0: IC2.33 (PM0), PM0_2.2 (C)
/MeteringIC1/PM1: IC2.34 (PM1), PM1_2.2 (C)
/PowerBoard/I1N_0: C40.1, J9.1, R73.1
/PowerBoard/I1N_1: C46.1, J9.7, R88.1
/PowerBoard/I1P_0: C39.1, J9.2, R72.1
/PowerBoard/I1P_1: C45.1, J9.8, R87.1
/PowerBoard/I2N_0: C42.1, J9.3, R75.1
/PowerBoard/I2N_1: C48.1, J9.9, R90.1
/PowerBoard/I2P_0: C41.1, J9.4, R74.1
/PowerBoard/I2P_1: C47.1, J9.10, R89.1
/PowerBoard/I3N_0: C44.1, J9.5, R77.1
/PowerBoard/I3N_1: C50.1, J9.11, R92.1
/PowerBoard/I3P_0: C43.1, J9.6, R76.1
/PowerBoard/I3P_1: C49.1, J9.12, R91.1
/PowerBoard/IA0+: J4.1, R63.1, R66.1, R72.2
/PowerBoard/IA0-: J4.2, R63.2, R67.2, R73.2
/PowerBoard/IA1+: J4.7, R78.1, R81.1, R87.2
/PowerBoard/IA1-: J4.8, R78.2, R82.2, R88.2
/PowerBoard/IB0+: J4.3, R64.1, R68.1, R74.2
/PowerBoard/IB0-: J4.4, R64.2, R69.2, R75.2
/PowerBoard/IB1+: J4.9, R79.1, R83.1, R89.2
/PowerBoard/IB1-: J4.10, R79.2, R84.2, R90.2
/PowerBoard/IC0+: J4.5, R65.1, R70.1, R76.2
/PowerBoard/IC0-: J4.6, R65.2, R71.2, R77.2
/PowerBoard/IC1+: J4.11, R80.1, R85.1, R91.2
/PowerBoard/IC1-: J4.12, R80.2, R86.2, R92.2
/PowerBoard/U1: C1.1, J2.1, J2.2, PS1.1 (AC/L), R1.1, RV1.2
/PowerBoard/U1_S: C3.1, J9.14, R10.2, R13.1
/PowerBoard/U1_{1}: R1.2, R4.1
/PowerBoard/U1_{2}: R4.2, R7.1
/PowerBoard/U1_{3}: R7.2, R10.1
/PowerBoard/U2: J2.3, J2.4, R2.1, RV2.2
/PowerBoard/U2_S: C4.1, J9.16, R11.2, R14.1
/PowerBoard/U2_{1}: R2.2, R5.1
/PowerBoard/U2_{2}: R5.2, R8.1
/PowerBoard/U2_{3}: R8.2, R11.1
/PowerBoard/U3: J2.5, R3.1, RV3.2
/PowerBoard/U3_S: C5.1, J9.18, R12.2, R15.1
/PowerBoard/U3_{1}: R3.2, R6.1
/PowerBoard/U3_{2}: R6.2, R9.1
/PowerBoard/U3_{3}: R9.2, R12.1
/PowerBoard/UN: F1.1, J2.6, RV1.1, RV2.1, RV3.1
/PowerBoard/UN_{in1}: C1.2, F1.2, L1.1
/U1_S: IC1.13 (V1P), IC2.13 (V1P), J10.13
/U2_S: IC1.15 (V2P), IC2.15 (V2P), J10.15
/U3_S: IC1.17 (V3P), IC2.17 (V3P), J10.17
GND: C2.2, C6.2, C17.1, D1.1 (A1), J1.1, J8.2, J8.9, J9.19, J9.20, J10.19, J10.20, PS1.3 (-Vout), PS2.1 (-Vin), R22.2, U5.8 (GND1)
GNDREF: C3.2, C4.2, C5.2, C7.1, C8.1, C9.1, C10.1, C11.1, C12.1, C13.2, C14.2, C15.1, C16.2, C18.1, C23.1, C24.1, C25.1, C26.1, C27.1, C28.1, C29.2, C30.2, C31.1, C32.2, C39.2, C40.2, C41.2, C42.2, C43.2, C44.2, C45.2, C46.2, C47.2, C48.2, C49.2, C50.2, IC1.2 (AGND), IC1.9 (IC), IC1.10 (IC), IC1.12 (AGND), IC1.19 (DGND), IC1.32 (TEST), IC1.36 (IC), IC1.44 (DGND), IC1.47 (DGND), IC2.2 (AGND), IC2.9 (IC), IC2.10 (IC), IC2.12 (AGND), IC2.19 (DGND), IC2.32 (TEST), IC2.36 (IC), IC2.44 (DGND), IC2.47 (DGND), J3.1, J7.3, J9.17, J10.18, J11.3, J12.2, L1.2, PM0_1.3 (B), PM0_2.3 (B), PM1_1.3 (B), PM1_2.3 (B), PS1.2 (AC/N), PS2.3 (-Vout), R13.2, R14.2, R15.2, R16.2, R17.2, R18.2, R34.2, R35.2, R36.2, R66.2, R67.1, R68.2, R69.1, R70.2, R71.1, R81.2, R82.1, R83.2, R84.1, R85.2, R86.1, U5.9 (GND2), Y1.2, Y1.4, Y2.2, Y2.4
unnamed: C13.1, C14.1, IC1.42 (VDD18), IC1.43 (VDD18)
unnamed: C29.1, C30.1, IC2.42 (VDD18), IC2.43 (VDD18)
unnamed: D2.2 (A), R22.1
unnamed: IC1.27 (CF3), TP2.1
unnamed: IC1.28 (CF4), TP6.1
unnamed: IC1.20 (OSCI), Y1.1
unnamed: IC1.21 (OSCO), Y1.3
unnamed: C10.2, IC1.14 (V1N), R16.1
unnamed: C12.2, IC1.16 (V2N), R17.1
unnamed: C15.2, IC1.18 (V3N), R18.1
unnamed: C7.2, C9.2, IC1.11 (VREF)
unnamed: IC2.27 (CF3), TP11.1
unnamed: IC2.28 (CF4), TP15.1
unnamed: IC2.20 (OSCI), Y2.1
unnamed: IC2.21 (OSCO), Y2.3
unnamed: C26.2, IC2.14 (V1N), R34.1
unnamed: C28.2, IC2.16 (V2N), R35.1
unnamed: C31.2, IC2.18 (V3N), R36.1
unnamed: C23.2, C25.2, IC2.11 (VREF)
unnamed: J8.3, U5.2 (INA)
unnamed: J8.4, U5.3 (INB)
unnamed: J8.5, U5.4 (INC)
unnamed: J8.6, U5.5 (IND)
unnamed: J8.7, U5.6 (INE)
unnamed: J8.8, U5.7 (OUTF)

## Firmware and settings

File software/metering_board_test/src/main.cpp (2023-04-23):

#include <Arduino.h>
#include <SPI.h>
#include <ATM90E32.h>


ATM90E32 energy_meter1{};
ATM90E32 energy_meter2{};


void setup() {
 Serial.begin(115200);
   while (!Serial) {
    ; // wait for serial port to connect. Needed for native USB
  }

    const int CS_0_pin = 5;
    const int CS_1_pin = 4;

    const int lineFreq = 4231;
    const int pga_gain = 0;
    const int VoltageGain = 7305;
    const int CurrentGain = 27961;
    energy_meter1.begin(CS_0_pin, lineFreq, pga_gain, VoltageGain, CurrentGain, CurrentGain, CurrentGain);
    energy_meter2.begin(CS_1_pin, lineFreq, pga_gain, VoltageGain, CurrentGain, CurrentGain, CurrentGain);

 }

void loop() {
  // put your main code here, to run repeatedly:

  while (1) {
    double voltage1 = energy_meter1.GetLineVoltageA();
    double voltage1v2 = energy_meter1.GetLineVoltageA();
    double voltage2 = energy_meter1.GetLineVoltageB();
    double voltage3 = energy_meter1.GetLineVoltageC();
    Serial.printf("[1] U1: %6.2f %6.2f V  U2: %6.2f V  U3: %6.2f V\n", voltage1, voltage1v2, voltage2, voltage3);
  
    voltage1 = energy_meter2.GetLineVoltageA();
    voltage2 = energy_meter2.GetLineVoltageB();
    voltage3 = energy_meter2.GetLineVoltageC();
    Serial.printf("[2] U1: %6.2f V  U2: %6.2f V  U3: %6.2f V\n", voltage1, voltage2, voltage3);


    Serial.printf("[1] TEMP: %7.2f\n", energy_meter1.GetTemperature());
    Serial.printf("[2] TEMP: %7.2f\n", energy_meter2.GetTemperature());

#if 0
    double CT1 = energy_meter.GetLineCurrentA();
    double CT2 = energy_meter.GetLineCurrentB();
    double CT3 = energy_meter.GetLineCurrentC();
    Serial.printf("I1: %6.2f V  I2: %6.2f V  I3: %6.2f V\n", CT1, CT2, CT3);
    
    double watts1 = energy_meter.GetActivePowerA();
    double watts2 = energy_meter.GetActivePowerB();
    double watts3 = energy_meter.GetActivePowerC();
    Serial.printf("P1: %6.2f W  P2: %6.2f W  P3: %6.2f W\n", watts1, watts2, watts3);
    //double totalWatts = energy_meter.GetTotalActivePower();
#endif
    Serial.printf("---\n");

    delay(1000);
  }

}

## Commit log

2023-04-23 hardware: add full kicad project
    [B72650M0271K072.stp, din_energy_meter.kicad_pcb, din_energy_meter.kicad_sch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]
2023-04-23 hardware: add v0.4 production outputs
    [din_energy_meter.kicad_pcb, din_energy_meter.kicad_sch, din_energy_meter.xlsx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]
2023-04-23 software: add basic metering board test
    Using PlatformIO Android Framework
